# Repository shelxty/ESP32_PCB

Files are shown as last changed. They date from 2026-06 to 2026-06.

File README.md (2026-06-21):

# ESP32-C3 USB-C Devboard 

This is a custom 4-layer ESP32-C3 devboard built from scratch in KiCad, built around the ESP32-C3-WROOM-02. It's my second devboard (if a regulator can be counted as a devboard) with a full breakout of GPIOs and reset/boot buttons.

## Motivation 
This is my second-ever PCB; I built it to follow up on my first project. I've been interested in how ESP32s work so I thought this would be the best way to explore it! This would be an actual useful, purposeful tool that I'd be able to use in built projects as well. It also pushed me to learn new skills, like ESD protection and multi-layer board design (well, multi-layer as in 4 instead of 2). 

## How the Components Work 

| **Designator** | **Part** | **Purpose** | 
|---|---|---|
| U3 | ESP32-C3-WROOM-02 | The brain of the board basically (it's a RISC-V microcontroller module that has integrated WiFi & bluetooth, along with an antenna) | 
| J1 | 16-pin USB-C receptacle | Power entry (it takes in 5V) | 
| J2, J3 | 8-pin headers on the left & right side, respectively | Breaks out the GPIO pins | 
| U1 | USBLC6-2SC6 | Dual line ESD protection IC that suppresses voltage spikes before they reach the microcontroller | 
| D1 | PESD5V0L1ULD | A TVS diode that protects the voltage line (5V) from any ESD/transient voltage spikes that enter from the USB receptacle | 
| R3 | 0Ω resistor | Basically a routing jumper so that I don't have to remove a trace | 
| U2 | AP2112K-3.3 | Fixed 3.3V, 600mA LDO regulator (it basically takes the 5V input and regulates it into a stable 3.3V rail) | 
| C1, C2 | 4.7uF capacitors | These are input and output capacitors built around the regulator that smooths the 5V input and the regulated 3.3V output | 
| C3, C4, C5 | 4.7uF capacitors | Other decoupline capacitors except these around the module's power pins, so the supply is stable even during WiFi bursts | 
| C9, C10 | 100nF capacitors | These are high-frequency decoupling capacitors that are placed close to the regulator's pins (they filter out noise) | 
| R5 | 10kΩ resistor | This is a pull-up resistor that supports the enable (EN) line | 
| R7, R8 | 10kΩ resistor | These are two other pull-up resistors except they support different GPIO lines | 
| R1, R2 | 5.1kΩ resistor | Resistors on the RESET and BOOT button lines, respectively | 
| SW1 | "RESET" Push Button | Basically just... resets the chip... yeah. | 
| SW2 | "BOOT" Push Button | Pulls IO9 (the strapping pin that selects boot mode, as opposed to UART download mode) low when it's pressed | 
| R9 | 10kΩ resistor | This one is another pull-up resistor but it specifically works on the IO9 boot/strapping line (so the chip should boot normally if the BOOT button isn't being pressed | 
| Y1 | Crystal | An external crystal that provides a precise clock reference | 

**Hardware**
- Tool: KiCad 10
- Board: 4-layer PCB (F.Cu / In1.Cu / In2.Cu / B.Cu)
- Microcontroller: ESP32-C3-WROOM-02 RISC-V, WiFi + Bluetooth
- Regulator: AP2112K-3.3, 600mA LDO
- USB protection: USBLC6-2SC6 (data line ESD) + PESD5V0L1ULD (VBUS TVS diode)
- Power input: USB-C (5V)
- GPIOs: 16 pins broken out across two 8-pin 2.54mm headers (J2, J3)
- Controls: Reset button (SW1), Boot button (SW2)

## PCB Design 


_Schematic of the board -- I made sure to add comments & my own personal text for beginners like me_



_PCB design_



_A 3D view of the actual thing_

## Bill of Materials 
| **Item** |	**Description** |	**Reference** |	**Qty** |	**MOQ** |	**Value** |	**Per Unit Price ($)** |	**Total Price ($)** |	**Footprint** |	**MPN** |	**URL** | 
|---|---|---|-----|-----|---|---|---|---|-----|-----|
| 4u7 Capacitor |	Unpolarized capacitor |	C1,C2,C3,C4,C5 |	5 |	10 |	4u7 |	0.0505 |	0.51 |	Capacitor_SMD:C_0805_2012Metric |	CL21A475KBQNNNE |	[Link](https://www.lcsc.com/product-detail/C98192.html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) |
| 100n Capacitor |	Unpolarized capacitor |	C6,C9,C10 |	3 |	10 |	100n |	0.0192 |	0.19 |	Capacitor_SMD:C_0201_0603Metric |	0805B104K500CT |	[Link](https://www.lcsc.com/product-detail/C83055.html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) |
| Capacitor |	Unpolarized capacitor |	C7,C8,R4 |	3 |	100 |	0n |	0.0052 |	0.52 |	Capacitor_SMD:C_0201_0603Metric |	TCC0805X7R501K500DT |	[Link](https://www.lcsc.com/product-detail/C5375938.html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) |
| ESD Diode |	Low capacitance unidirectional ESD protection diode, 5V, SOD-882D |	D1 |	1 |	5 |	PESD5V0L1ULD |	0.0978 |	0.49 |	Diode_SMD:D_SOD-882D |	PESD5V0L1ULD,315 |	[Link](https://www.lcsc.com/product-detail/C552557.html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) | 
| USB-C Receptacle |	USB 2.0-only 16P Type-C Receptacle connector |	J1 |	1 |	5 |	USB_C_Receptacle_USB2.0_16P |	0.099 |	0.5 |	Connector_USB:USB_C_Receptacle_G-Switch_GT-USB-7010ASV |	USB-TYPE-C-016 |	[Link](https://www.lcsc.com/product-detail/C2927036.html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) |
| 1x08 Connector |	Generic connector, single row, 01x08 |	J2,J3 |	2 |	5 |	Conn_01x08_Pin |	0.558 |	2.79 |	Connector_PinHeader_2.54mm:PinHeader_1x08_P2.54mm_Vertical |	N/A |	[Link](https://www.aliexpress.us/item/3256807202794047.html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) | 
| Resistor |	Resistor |	R1,R2 |	2 |	100 |	5k1 |	0.0022 |	0.22 |	Resistor_SMD:R_0805_2012Metric |	FRC0805J512TS |	[Link](https://www.lcsc.com/product-detail/C2930296.html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) |
| Resistor |	Resistor |	R3 |	1 |	100 |	0R |	0.003 |	0.3 |	Resistor_SMD:R_0805_2012Metric |	0805W8F0000T5E |	[Link](https://www.lcsc.com/product-detail/C17477.html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) |
| Resistor |	Resistor |	R5,R7,R8,R9 |	4 |	100 |	10k |	0.0031 |	0.31 |	Capacitor_SMD:C_0201_0603Metric |	FRC0805J103TS |	[Link](https://www.lcsc.com/product-detail/C2930231.html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) | 
| Resistor |	Resistor |	R4, R6 |	2 |	100 |	100R |	0.0031 |	0.31 |	Capacitor_SMD:C_0201_0603Metric |	FRC0805J101 TS |	[Link](https://www.lcsc.com/product-detail/C2907294.html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) | 
| Push Button |	Push button switch, generic, two pins |	SW1,SW2 |	2 |	10 |	SW_Push |	0.053 |	0.53 |	Button_Switch_SMD:SW_SPST_B3U-1000P |	TS-1088-AR02016 |	[Link](https://www.lcsc.com/product-detail/C720477.html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) | 
| ESD Diode |	Very low capacitance ESD protection diode, 2 data-line, SOT-23-6 |	U1 |	1 |	10 |	USBLC6-2SC6 |	0.041 |	0.41 |	Package_TO_SOT_SMD:SOT-23-6 |	USBLC6-2SC6 |	[Link](https://www.lcsc.com/product-detail/C2827654.html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) | 
| Linear Regulator |	600mA low dropout linear regulator, with enable pin, 3.8V-6V input voltage range, 3.3V fixed positive output, SOT-23-5 |	U2 |	1 |	5 |	AP2112K-3.3 |	0.1093 |	0.55 |	Package_TO_SOT_SMD:SOT-23-5 |	AP2112K-3.3TRG1 |	[Link](https://www.lcsc.com/product-detail/C23380830.html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) | 
| ESP32-C3 |	802.11 b/g/n WiÂ­Fi and Bluetooth 5 module, ESP32Â­C3 SoC, RISCÂ­V microprocessor, On-board antenna |	U3 |	1 |	1 |	ESP32-C3-WROOM-02 |	3.33 |	3.33 |	RF_Module:ESP32-C3-WROOM-02 |	ESP32-C3-WROOM-02-H4 |	[Link](https://www.lcsc.com/product-detail/C2944070.html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) | 
| Crystal |	Two pin crystal |	Y1 |	1 |	5 |	32.768kHz |	0.2461 |	1.23 |	Crystal:Crystal_SMD_3215-2Pin_3.2x1.5mm |	3608S-32.768DTTLLL-R35L |	[Link](https://www.lcsc.com/product-detail/C42392410.html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) | 
| **Total** | | | 	**30** |	**566** | | |		**12.19**			| 

ESP32 Custom Devboard - Shelley Ma - Fallout Zine

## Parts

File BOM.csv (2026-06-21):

Item | Description | Reference | Qty | MOQ | Value | Per Unit Price ($) | Total Price ($) | Footprint | MPN | URL
4u7 Capacitor | Unpolarized capacitor | C1,C2,C3,C4,C5 | 5 | 10 | 4u7 | 0.0505 | 0.51 | Capacitor_SMD:C_0805_2012Metric | CL21A475KBQNNNE | https://www.lcsc.com/product-detail/C98192.html?s_z=s_c_Ceramic%2520Capacitors
100n Capacitor | Unpolarized capacitor | C6,C9,C10 | 3 | 10 | 100n | 0.0192 | 0.19 | Capacitor_SMD:C_0201_0603Metric | 0805B104K500CT | https://www.lcsc.com/product-detail/C83055.html?s_z=s_c_Ceramic%2520Capacitors
Capacitor | Unpolarized capacitor | C7,C8,R4 | 3 | 100 | 0n | 0.0052 | 0.52 | Capacitor_SMD:C_0201_0603Metric | TCC0805X7R501K500DT | https://www.lcsc.com/product-detail/C5375938.html
ESD Diode | Low capacitance unidirectional ESD protection diode, 5V, SOD-882D | D1 | 1 | 5 | PESD5V0L1ULD | 0.0978 | 0.49 | Diode_SMD:D_SOD-882D | PESD5V0L1ULD,315 | https://www.lcsc.com/product-detail/C552557.html?s_z=s_p_PESD5V0L1ULD%252C315
USB-C Receptacle | USB 2.0-only 16P Type-C Receptacle connector | J1 | 1 | 5 | USB_C_Receptacle_USB2.0_16P | 0.099 | 0.5 | Connector_USB:USB_C_Receptacle_G-Switch_GT-USB-7010ASV | USB-TYPE-C-016 | https://www.lcsc.com/product-detail/C2927036.html?s_z=s_p_USB-TYPE-C-016
1x08 Connector | Generic connector, single row, 01x08 | J2,J3 | 2 | 5 | Conn_01x08_Pin | 0.558 | 2.79 | Connector_PinHeader_2.54mm:PinHeader_1x08_P2.54mm_Vertical | N/A | https://www.aliexpress.us/item/3256807202794047.html?scm_id=1007.40050.354490.0&scm-url=1007.40050.354490.0
Resistor | Resistor | R1,R2 | 2 | 100 | 5k1 | 0.0022 | 0.22 | Resistor_SMD:R_0805_2012Metric | FRC0805J512TS | https://www.lcsc.com/product-detail/C2930296.html?s_z=s_q_t_RESISTOR
Resistor | Resistor | R3 | 1 | 100 | 0R | 0.003 | 0.3 | Resistor_SMD:R_0805_2012Metric | 0805W8F0000T5E | https://www.lcsc.com/product-detail/C17477.html?s_z=s_q_t_RESISTOR
Resistor | Resistor | R5,R7,R8,R9 | 4 | 100 | 10k | 0.0031 | 0.31 | Capacitor_SMD:C_0201_0603Metric | FRC0805J103TS | https://www.lcsc.com/product-detail/C2930231.html?s_z=s_q_t_RESISTOR
Resistor | Resistor | R4, R6 | 2 | 100 | 100R | 0.0031 | 0.31 | Capacitor_SMD:C_0201_0603Metric | FRC0805J101 TS | https://www.lcsc.com/product-detail/C2907294.html
Push Button | Push button switch, generic, two pins | SW1,SW2 | 2 | 10 | SW_Push | 0.053 | 0.53 | Button_Switch_SMD:SW_SPST_B3U-1000P | TS-1088-AR02016 | https://www.lcsc.com/product-detail/C720477.html?s_z=s_q_p_PUSH%2520BUTTON%2520SWITCH
ESD Diode | Very low capacitance ESD protection diode, 2 data-line, SOT-23-6 | U1 | 1 | 10 | USBLC6-2SC6 | 0.041 | 0.41 | Package_TO_SOT_SMD:SOT-23-6 | USBLC6-2SC6 | https://www.lcsc.com/product-detail/C2827654.html?s_z=s_p_USBLC6-2SC6
Linear Regulator | 600mA low dropout linear regulator, with enable pin, 3.8V-6V input voltage range, 3.3V fixed positive output, SOT-23-5 | U2 | 1 | 5 | AP2112K-3.3 | 0.1093 | 0.55 | Package_TO_SOT_SMD:SOT-23-5 | AP2112K-3.3TRG1 | https://www.lcsc.com/product-detail/C23380830.html?s_z=s_q_AP2112K-3.3
ESP32-C3 | 802.11 b/g/n Wi-Fi and Bluetooth 5 module, ESP32-C3 SoC, RISC-V microprocessor, On-board antenna | U3 | 1 | 1 | ESP32-C3-WROOM-02 | 3.33 | 3.33 | RF_Module:ESP32-C3-WROOM-02 | ESP32-C3-WROOM-02-H4 | https://www.lcsc.com/product-detail/C2944070.html?s_z=n_q_ESP32-C3-WROOM-02
Crystal | Two pin crystal | Y1 | 1 | 5 | 32.768kHz | 0.2461 | 1.23 | Crystal:Crystal_SMD_3215-2Pin_3.2x1.5mm | 3608S-32.768DTTLLL-R35L | https://www.lcsc.com/product-detail/C42392410.html?s_z=n_q_t_crystal
Total |  |  | 30 | 566 |  |  | 12.19

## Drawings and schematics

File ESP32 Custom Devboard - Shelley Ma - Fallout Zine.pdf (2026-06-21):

# eSP32-C3 USB-C

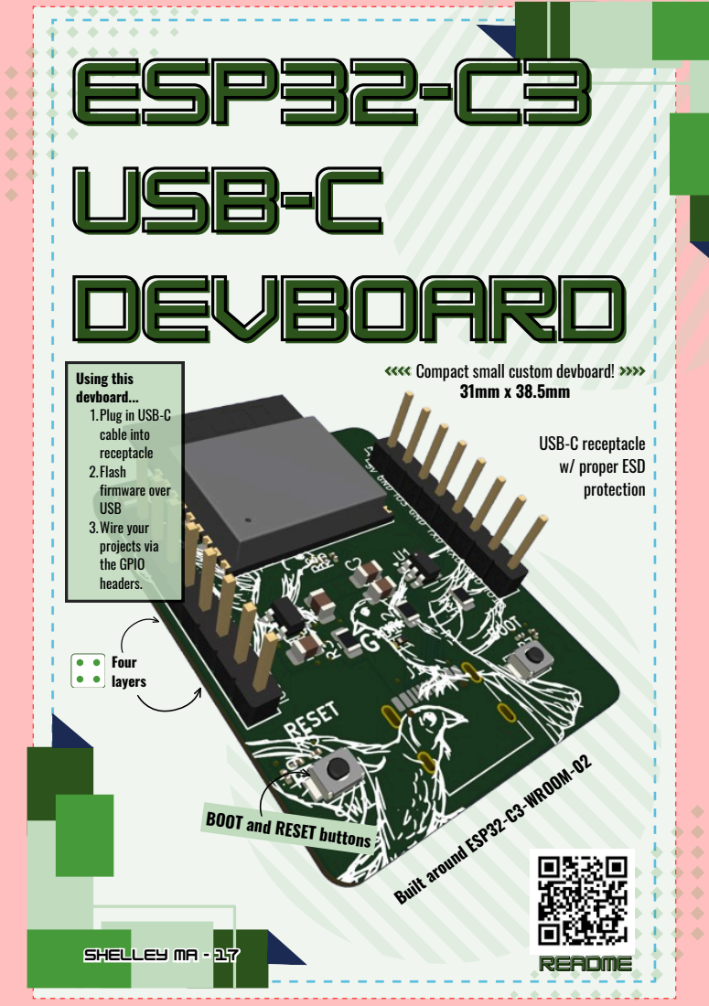
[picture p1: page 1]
Four layers; Devboard; eeSSPP3322--CC33 USB--C DDeevvbbooaarrdd; RREEAADDMMEE; ssHHEELLLLEEYY mmAA -- 1177; USB-C receptacle w/ proper ESD protection

Compact small custom devboard!

Using this
devboard...
1.Plug in USB-C
cable into
receptacle
2.Flash
firmware over
USB
3.Wire your
projects via
the GPIO
headers.

Built around ESP32-C3-WROOM-02

BOOT and RESET buttons

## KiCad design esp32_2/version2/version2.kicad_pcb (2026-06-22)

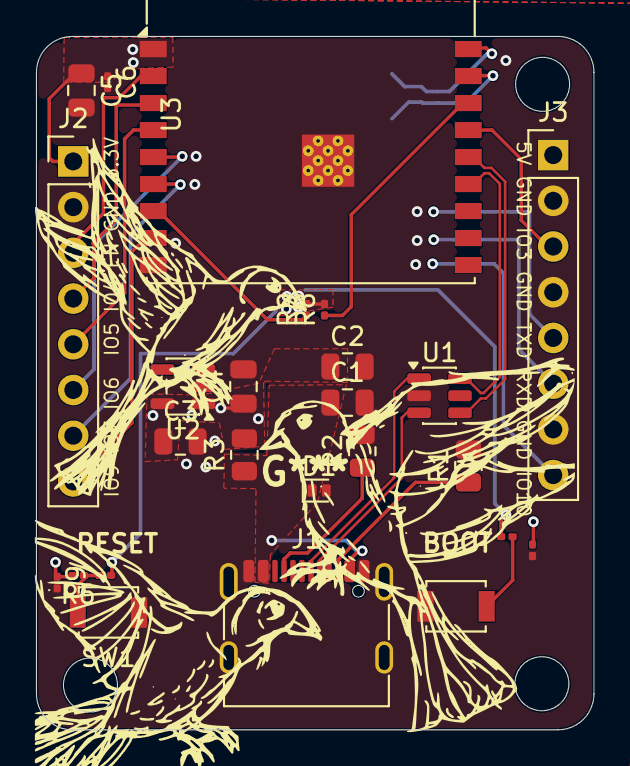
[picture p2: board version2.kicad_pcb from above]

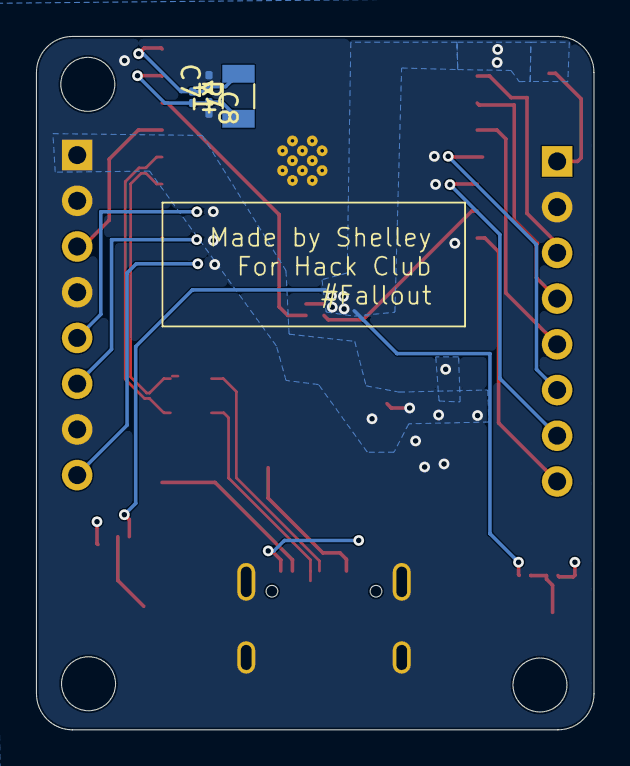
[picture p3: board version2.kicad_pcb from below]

Board: 4 copper layers, 31.0 x 38.5 mm, 29 parts (4 on the bottom side), 23 nets.

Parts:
C1, C2, C3, C4, C5: 4u7; C_0805_2012Metric
C6, C9, C10: 100n; C_0201_0603Metric
C7, C8: TBD; C_0201_0603Metric
D1: PESD5V0L1ULD; D_SOD-882D
J1: USB_C_Receptacle_USB2.0_16P; USB_C_Receptacle_G-Switch_GT-USB-7010ASV
J2, J3: Conn_01x08_Pin; PinHeader_1x08_P2.54mm_Vertical
R1, R2: 5k1; R_0805_2012Metric
R3: 0R; R_0805_2012Metric
R4: TBD; C_0201_0603Metric
R5, R7, R8, R9: 10k; C_0201_0603Metric
R6: 100R; C_0201_0603Metric
SW1, SW2: SW_Push; SW_SPST_B3U-1000P
U1: USBLC6-2SC6; SOT-23-6
U2: AP2112K-3.3; SOT-23-5
U3: ESP32-C3-WROOM-02
Y1: Crystal; Crystal_SMD_3215-2Pin_3.2x1.5mm

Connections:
+3V3: C5.1, C6.1, J2.1, R5.2, R7.2, R8.2, R9.2, U3.1 (3V3)
+5V: C2.1, C3.1, C4.1, J3.1, R3.2, U2.1 (VIN), U2.3 (EN), U2.5 (VOUT)
/D+: J1.A6 (D+), J1.B6 (D+), U1.3 (I/O2)
/D-: J1.A7 (D-), J1.B7 (D-), U1.1 (I/O1)
EN: C9.1, J2.3, R6.2, U3.2 (EN)
GND: C1.2, C2.2, C3.2, C4.2, C5.2, C6.2, C7.2, C8.2, C9.2, C10.2, D1.2 (A), J1.A1 (GND), J1.A12 (GND), J1.B1 (GND), J1.B12 (GND), J1.SH (SHIELD), J2.2, J3.2, J3.4, J3.7, R1.2, R2.2, SW1.1, SW2.1, U1.2 (GND), U2.2 (GND), U3.9 (GND), U3.19 (GND)
IO2: R8.1, U3.16 (IO2)
IO3: J3.3, U3.15 (IO3)
IO4: J2.4, U3.3 (IO4)
IO5: J2.5, U3.4 (IO5)
IO6: J2.6, U3.5 (IO6)
IO7: J2.7, U3.6 (IO7)
IO8: R9.1, U3.7 (IO8)
IO9: C10.1, J2.8, R7.1, SW2.2, U3.8 (IO9)
IO10: J3.8, U3.10 (IO10)
unnamed: J1.A5 (CC1), R2.1
unnamed: J1.B5 (CC2), R1.1
unnamed: R5.1, R6.1, SW1.2
unnamed: C7.1, R4.1, U3.18 (IO0), Y1.1
unnamed: C8.1, R4.2, U3.17 (IO1), Y1.2
USB_D+: U1.4 (I/O2), U3.14 (IO19)
USB_D-: U1.6 (I/O1), U3.13 (IO18)
VBUS: C1.1, D1.1 (K), J1.A4 (VBUS), J1.A9 (VBUS), J1.B4 (VBUS), J1.B9 (VBUS), R3.1

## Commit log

2026-05-14 wiring, connections between cp2104 and the usb c receptacle and stuffs
    [esp32pcb.kicad_sch]
2026-06-17 finished schematic v2
    [esp32mini.kicad_sch, untitled.kicad_sch, version2.kicad_pcb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]
2026-06-19 added copper fill vbus
    [esp32mini.kicad_sch, untitled.kicad_sch, version2.kicad_pcb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]
2026-06-20 added some more routing and copper filling for 5v and 3v3
    [version2.kicad_pcb]
2026-06-20 fixed up some other basic routing issues i hate this
    [version2.kicad_pcb]
2026-06-20 more routing more vias more visas (not)
    [version2.kicad_pcb]
2026-06-20 i feel stupid because the reason everything was breaking because i added an extra gnd pin in my schematic when i wasn't supposed to
    [version2.kicad_sch]
2026-06-20 finished routing
    [version2.kicad_pcb]
2026-06-20 finished routing and finished pcb design!
    [version2.kicad_pcb]
2026-06-21 Delete esp32pcb directory
    This was my version 1 and therefore doesn't need to be here.
    [esp32pcb.kicad_pcb, esp32pcb.kicad_sch]
2026-06-21 BOM
    bom
    [version2.csv]
2026-06-21 renamed bom to bom
    [BOM.csv]
2026-06-22 edited mounting holes
    [version2.csv, version2.kicad_pcb, version2.kicad_sch]
2026-06-22 oops some formatting stuff
    [version2.kicad_pcb]
